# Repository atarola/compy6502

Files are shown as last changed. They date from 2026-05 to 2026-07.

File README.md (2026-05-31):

# compy6502

`compy6502` is an early-stage 6502 homebrew computer project. The long-term
goal is to build enough hardware and firmware to run Tetris on the machine.

The design follows the spirit of Ben Eater-style breadboard/modular 6502
systems for simplicity and debuggability, but uses a different memory map based
on the MMU/address-decoder architecture in `docs/mmu.png`.

The repo currently includes KiCad hardware designs, early ROM bring-up
firmware, build/write scripts, emulator test scaffolding, and architecture
reference images in `docs/`.

## Memory Map

The intended memory map is:

```text
$0000-$BFFF  RAM
$C000-$C0FF  I/O page
$C100-$FFFF  ROM
```

The I/O page is split into four 64-byte device slots:

```text
$C000-$C03F  IO0B
$C040-$C07F  IO1B
$C080-$C0BF  IO2B
$C0C0-$C0FF  IO3B
```

The linker script currently uses `$8000-$FFFF` as the 32 KB EEPROM image range
so CPU addresses map directly to the correct physical offsets on the chip.

## ROM Layout

The intended ROM organization is:

```text
$C100-$C1FF  public jump table
$C200-$DFFF  kernel routines and drivers
$E000-$EFFF  enhanced monitor
$F500-$FFF9  Wozmon fallback monitor
$FFFA-$FFFF  CPU vectors
```

## Credits

- `docs/mmu.png`: Mike McLaren, K8LH.
- `docs/Beater 02b.png`: Mike McLaren, K8LH.

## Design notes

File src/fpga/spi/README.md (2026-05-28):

# SPI Controller

The SPI Controller is a memory-mapped SPI peripheral for a 6502-style bus. It provides byte transfers, four programmable active-low chip-select outputs, and a shared tri-state 8-bit data bus that is only driven during read cycles.

Hardware note: the assembled board has the 6502 read/write strobes crossed relative to the original schematic labels. The FPGA top-level compensates for that wiring so the controller still sees the correct read and write edges.

## 1. Features
- 6502-compatible register interface.
- One-byte SPI transmit and receive register.
- Four active-low SPI chip-select outputs.
- Software-controlled chip-select hold.
- Shared tri-state external data bus.
- MSB-first SPI transfers.

## 2. External Signals
### 2.1 6502 Bus
| Signal | Pin | Direction | Description |
| --- | --- | --- | --- |
| `RESB` | `3` | In, active-low | Reset. |
| `CSB` | `14` | In, active-low | Selects this peripheral. |
| `RDB` | `5` | In, active-low | Read strobe. On the built board, this is the physical wire that the top-level routes to the controller write edge input. |
| `WRB` | `4` | In, active-low | Write strobe. On the built board, this is the physical wire that the top-level routes to the controller read edge input. |
| `REG_SELECT[1]` | `1` | In | Register select bit 1. |
| `REG_SELECT[0]` | `2` | In | Register select bit 0. |
| `DATA[7]` | `6` | Inout | Shared data bus bit 7. |
| `DATA[6]` | `7` | Inout | Shared data bus bit 6. |
| `DATA[5]` | `8` | Inout | Shared data bus bit 5. |
| `DATA[4]` | `9` | Inout | Shared data bus bit 4. |
| `DATA[3]` | `10` | Inout | Shared data bus bit 3. |
| `DATA[2]` | `11` | Inout | Shared data bus bit 2. |
| `DATA[1]` | `12` | Inout | Shared data bus bit 1. |
| `DATA[0]` | `13` | Inout | Shared data bus bit 0. |
| `DATA_OUT` | `15` | Out | High when the controller is driving `DATA[7:0]` toward the 6502 bus. |

### 2.2 SPI Bus
| Signal | Pin | Direction | Description |
| --- | --- | --- | --- |
| `SPI_CSB[0]` | `16` | Out, active-low | SPI chip select 0. |
| `SPI_CSB[1]` | `17` | Out, active-low | SPI chip select 1. |
| `SPI_CSB[2]` | `18` | Out, active-low | SPI chip select 2. |
| `SPI_CSB[3]` | `19` | Out, active-low | SPI chip select 3. |
| `SCK` | `20` | Out | SPI clock. |
| `MOSI` | `21` | Out | Master-out serial data. |
| `MISO` | `22` | In | Master-in serial data. |

### 2.3 Local Indicators
| Signal | Pin | Direction | Description |
| --- | --- | --- | --- |
| `LED` | `LED` | Out | High when any `SPI_CSB[3:0]` bit is low. |

## 3. Register Map
`REG_SELECT[1:0]` selects one of four register addresses.

| Address | Name | Read | Write |
| --- | --- | --- | --- |
| `0x00` | Data | Last received byte | Transmit byte and start transfer |
| `0x01` | Config | Current configuration | Update configuration |
| `0x02` | Status | Transfer status | Ignored |
| `0x03` | Reserved | `0x00` | Ignored |

## 4. Config Register
| Bits | Name | Description |
| --- | --- | --- |
| `1:0` | CS Select | Selects one of four SPI chip-select outputs. |
| `2` | CS Enable | `1` asserts selected chip select. `0` releases all chip selects. |
| `4:3` | Clock Select | Selects one of four SPI clock rates. |
| `7:5` | Reserved | Write `0`. |

Chip-select output when `CS Enable = 1`:

| CS Select | `SPI_CSB[3:0]` |
| --- | --- |
| `0b00` | `0b1110` |
| `0b01` | `0b1101` |
| `0b10` | `0b1011` |
| `0b11` | `0b0111` |

When `CS Enable = 0`, `SPI_CSB[3:0] = 0b1111`.

Clock rate setting:

| Setting | Result |
| --- | --- |
| `0b00` | `125 kHz` |
| `0b01` | `250 kHz` |
| `0b10` | `500 kHz` |
| `0b11` | `1 MHz` |

## 5. Status Register
| Bit | Name | Description |
| --- | --- | --- |
| `0` | Busy | `1` while a byte transfer is active. |
| `7:1` | Reserved | Reads as `0`. |

## 6. Bus Behavior
- The controller drives `DATA[7:0]` only during selected read cycles.
- `DATA_OUT` is high only during selected read cycles.
- During writes and unselected cycles, `DATA[7:0]` is high impedance from the controller side.
- Write effects are visible after a small number of FPGA clock cycles.
- Software should poll the Busy bit before assuming a byte transfer has completed.
- Writes to the Data register while Busy is set are ignored.

## 7. SPI Behavior
- Transfers are one byte at a time.
- Bits shift MSB first.
- Chip select is controlled by the Config register, not automatically by each byte transfer.
- For multi-byte devices, assert chip select, write/read the required bytes, then clear chip select.

## 8. Expected Transaction Example
Example: send command byte `0x9f` to device 0, then read three response bytes.

| Step | Register | RDB | WRB | Value | Expected effect |
| --- | --- | --- | --- | --- | --- |
| 1 | Config `0x01` | `1` | `0` | `0x04` | Assert `SPI_CSB[0]`; `SPI_CSB[3:0] = 0b1110`. |
| 2 | Data `0x00` | `1` | `0` | `0x9f` | Start transfer of command byte. |
| 3 | Status `0x02` | `0` | `1` | Read until Busy is `0` | Wait for command byte to finish. |
| 4 | Data `0x00` | `1` | `0` | `0x00` | Start transfer of first response byte. |
| 5 | Status `0x02` | `0` | `1` | Read until Busy is `0` | Wait for first response byte. |
| 6 | Data `0x00` | `0` | `1` | Read | Read first received byte. |
| 7 | Data `0x00` | `1` | `0` | `0x00` | Start transfer of second response byte. |
| 8 | Status `0x02` | `0` | `1` | Read until Busy is `0` | Wait for second response byte. |
| 9 | Data `0x00` | `0` | `1` | Read | Read second received byte. |
| 10 | Data `0x00` | `1` | `0` | `0x00` | Start transfer of third response byte. |
| 11 | Status `0x02` | `0` | `1` | Read until Busy is `0` | Wait for third response byte. |
| 12 | Data `0x00` | `0` | `1` | Read | Read third received byte. |
| 13 | Config `0x01` | `1` | `0` | `0x00` | Release all chip selects; `SPI_CSB[3:0] = 0b1111`. |

Each Data write shifts one byte out on `MOSI` and captures one byte from `MISO`. For read-only SPI responses, write `0x00` or another device-appropriate dummy byte to clock each response byte in.

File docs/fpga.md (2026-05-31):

# FPGA Development Environment

This project is expected to use a TinyFPGA BX for early SPI interface work. The
TinyFPGA BX uses a Lattice iCE40 FPGA, so the local toolchain is based on the
open-source iCE40 flow.

## Toolchain

Install the core tools with Homebrew:

```sh
brew install icarus-verilog verilator yosys nextpnr-ice40 icestorm surfer
```

The important tools are:

- `iverilog` / `vvp`: quick Verilog simulation.
- `verilator`: stronger linting and compiled simulation for larger tests.
- `yosys`: Verilog synthesis.
- `nextpnr-ice40`: place and route for Lattice iCE40 parts.
- `icepack`: bitstream packing, provided by `icestorm`.
- `surfer`: waveform viewer.

GTKWave is the traditional waveform viewer, but the Homebrew cask is currently
disabled. Use Surfer for waveform viewing unless that changes.

## TinyFPGA Programming From Windows

Build bitstreams from WSL/Ubuntu, but program the TinyFPGA BX from Windows.
WSL USB passthrough is unreliable with the BX bootloader timing.

Install `tinyprog` in Windows PowerShell:

```powershell
py -m pip install --user pipx
py -m pipx ensurepath
pipx install tinyprog
tinyprog --help
```

Close and reopen PowerShell after `ensurepath` if `pipx` is not found.

Build the FPGA target in WSL:

```sh
uv run doit fpga:build -t spi
```

Press reset on the TinyFPGA BX so the bootloader is active, then program the
bitstream from Windows:

```powershell
tinyprog -p "\\wsl.localhost\Ubuntu\home\atarola\code\compy6502\build\fpga\spi\spi.bin"
```

The USB serial device can disappear after programming because the bitstream
disables `USBPU`. Press reset before the next upload.

## Expected Flow

The normal edit/build/check loop is managed through `doit`:

```sh
uv run doit fpga:sim
uv run doit fpga:build
```

By default, non-programming actions run against all targets under `src/fpga/`.
Use `-t` to select one target:

```sh
uv run doit fpga:sim -t spi
uv run doit fpga:build -t spi
```

Supported FPGA actions are:

- `sim`: run the target testbench with Icarus Verilog.
- `synth`: synthesize `top.v` with Yosys.
- `pnr`: place and route with `nextpnr-ice40`.
- `pack`: pack the routed design with `icepack`.
- `build`: run `synth`, `pnr`, and `pack`.

Target directories use this layout:

```text
src/fpga/<target>/
  top.v
  pins.pcf
  *_tb.v
  other_design_modules.v
```

`fpga:sim` runs every `*_tb.v` testbench in the target. Synthesis reads all
`.v` files except testbenches and uses `top` as the top-level module.

The final bitstream for a target is written to:

```text
build/fpga/<target>/<target>.bin
```

For the spi target:

```text
build/fpga/spi/spi.bin
```

Program the TinyFPGA BX from Windows with `tinyprog` rather than passing USB
through WSL.

Conceptually, the flow is:

```text
write Verilog
simulate with iverilog or verilator
inspect waveforms with surfer
synthesize with yosys
place and route with nextpnr-ice40
pack a bitstream with icepack
program the TinyFPGA BX with tinyprog
```

The TinyFPGA BX guide is still useful for board-specific behavior and bootloader
details:

```text
https://tinyfpga.com/bx/guide.html
```

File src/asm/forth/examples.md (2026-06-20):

## Forth

def double 
  dup add
enddef

def next_term
  dup
  rot
  add
enddef

def fibonnacci
  1
  print
  1
  print
  begin
    next_term
    print
    dup
    B520
    eql
  until
enddef

def ifr      
  if 
    5555 print
    return 
  endif
  AAAA print
enddef

def ife
  if
    5555 print
  else
    AAAA print
  endif
enddef

def count
  0
  begin
    dup 5 eql eqz
  while
    print
    dup 1 add
  repeat
enddef

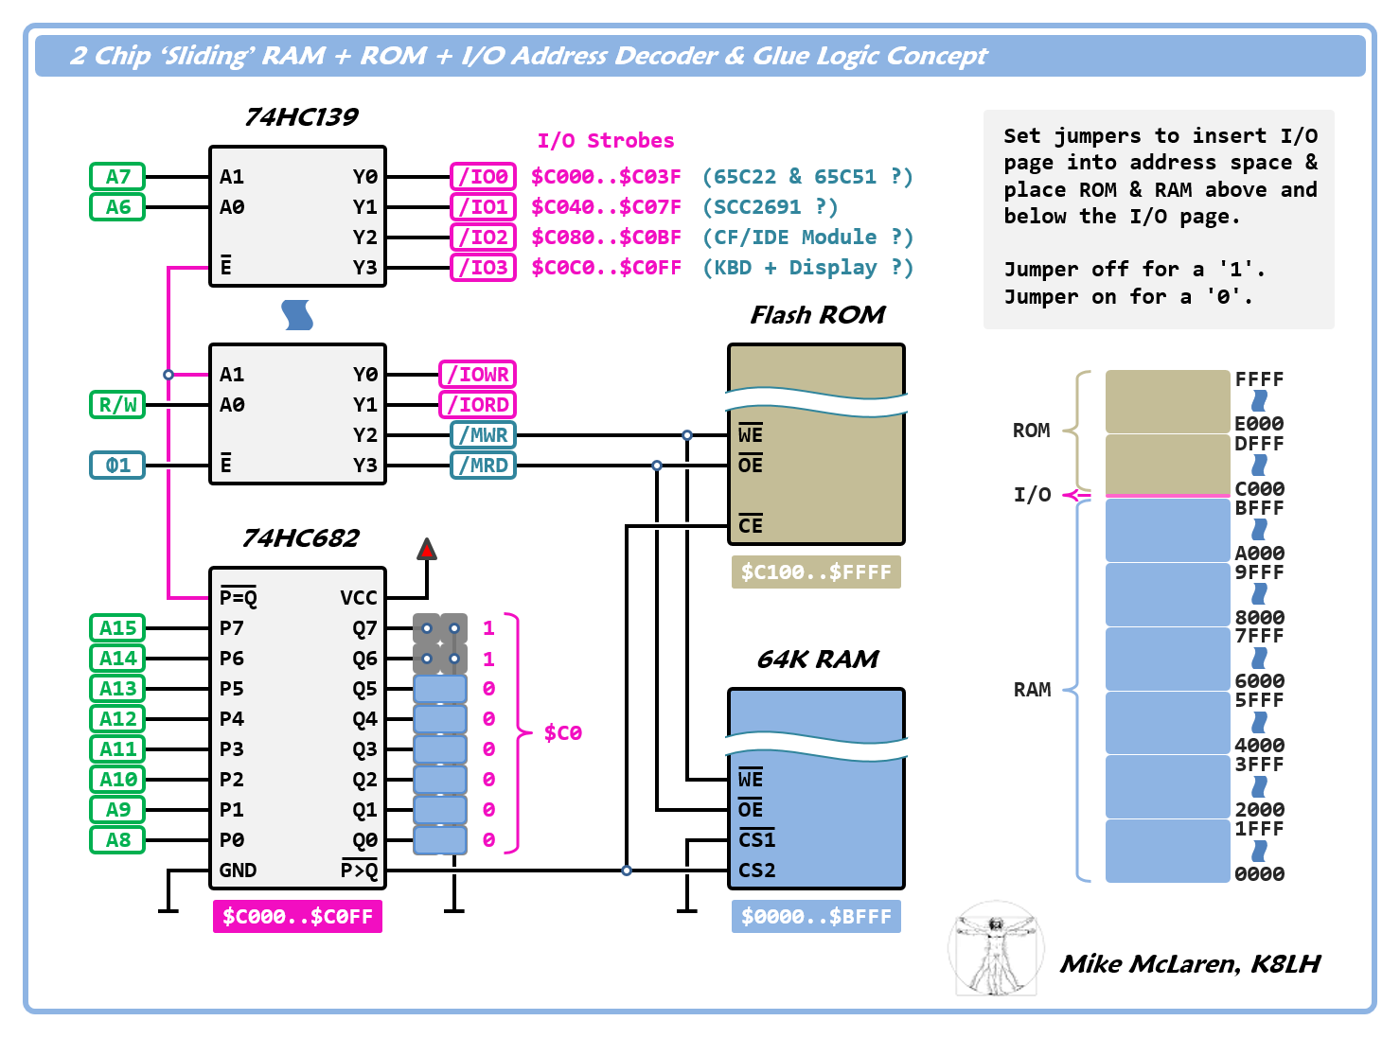
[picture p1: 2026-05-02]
docs/mmu.png

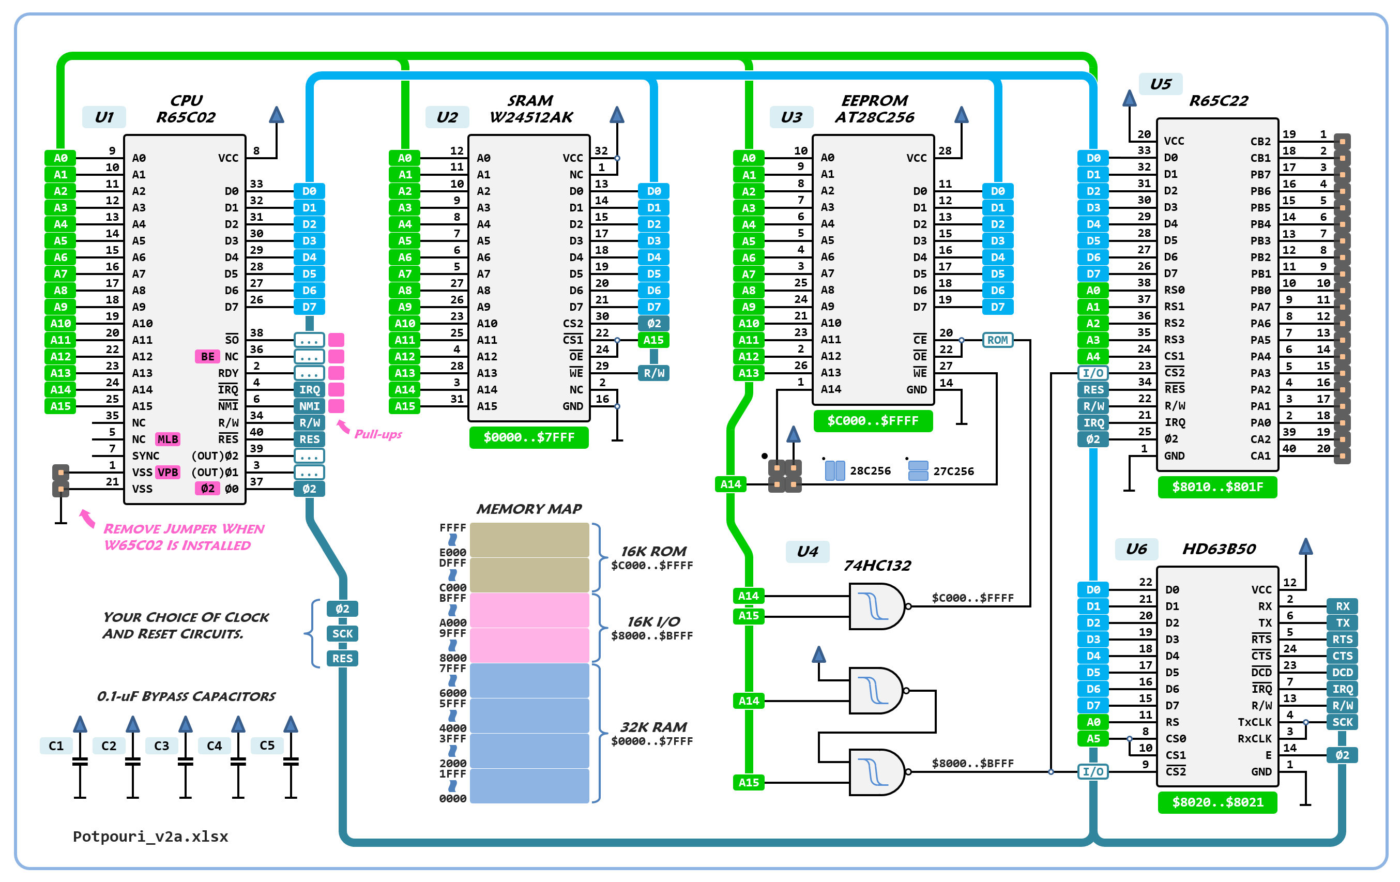
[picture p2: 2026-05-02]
docs/Beater 02b.png

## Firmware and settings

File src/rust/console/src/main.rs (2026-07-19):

#![no_std]
#![no_main]

mod display;
mod eve;
mod host;
mod keyboard;
mod keymap;
mod max3421e;
mod modes;

use embassy_embedded_hal::shared_bus::asynch::spi::SpiDeviceWithConfig;
use embassy_executor::Spawner;
use embassy_rp::bind_interrupts;
use embassy_rp::gpio::{Level, Output};
use embassy_rp::peripherals::{PIO0, SPI1, USB};
use embassy_rp::pio::{InterruptHandler as PioInterruptHandler, Pio};
use embassy_rp::spi::{Async, Config, Spi};
use embassy_rp::usb::{Driver, InterruptHandler};
use embassy_sync::blocking_mutex::raw::CriticalSectionRawMutex;
use embassy_sync::mutex::Mutex;
use embassy_time::Timer;
use embassy_usb_logger::{DummyHandler, LoggerState, UsbLogger};
use static_cell::StaticCell;

use {defmt_rtt as _, panic_probe as _};

bind_interrupts!(struct Irqs {
    PIO0_IRQ_0 => PioInterruptHandler<PIO0>;
    USBCTRL_IRQ => InterruptHandler<USB>;
});

static USB_LOGGER: UsbLogger<1024, DummyHandler> = UsbLogger::new();
static LOGGER_STATE: StaticCell<LoggerState<'static>> = StaticCell::new();

#[embassy_executor::task]
async fn usb_logger_task(state: &'static mut LoggerState<'static>, driver: Driver<'static, USB>) {
    USB_LOGGER.run(state, driver).await;
}

#[embassy_executor::task]
async fn blink_task(mut led: Output<'static>) {
    loop {
        led.set_high();
        Timer::after_millis(500).await;
        led.set_low();
        Timer::after_millis(500).await;
    }
}

static SPI1_BUS: StaticCell<Mutex<CriticalSectionRawMutex, Spi<'static, SPI1, Async>>> =
    StaticCell::new();

#[embassy_executor::main]
async fn main(spawner: Spawner) {
    let p = embassy_rp::init(Default::default());
    let pio0 = Pio::new(p.PIO0, Irqs);

    let spi1 = Spi::new(
        p.SPI1,
        p.PIN_14,
        p.PIN_15,
        p.PIN_8,
        p.DMA_CH0,
        p.DMA_CH1,
        Config::default(),
    );

    let spi1_bus = SPI1_BUS.init(Mutex::new(spi1));

    let usb_driver = Driver::new(p.USB, Irqs);
    let logger_state = LOGGER_STATE.init(LoggerState::new());

    unsafe {
        log::set_logger_racy(&USB_LOGGER).unwrap();
        log::set_max_level_racy(log::LevelFilter::Info);
    }

    spawner
        .spawn(usb_logger_task(logger_state, usb_driver))
        .unwrap();

    let eve_cs = Output::new(p.PIN_29, Level::High);
    let eve_pd = Output::new(p.PIN_6, Level::High);
    let eve_device = SpiDeviceWithConfig::new(spi1_bus, eve_cs, Config::default());

    let max_cs = Output::new(p.PIN_10, Level::High);
    let max_device = SpiDeviceWithConfig::new(spi1_bus, max_cs, Config::default());

    let led = Output::new(p.PIN_13, Level::Low);

    display::display_init(&spawner, eve_device, eve_pd).await;
    keyboard::keyboard_init(&spawner, max_device).await;
    host::host_init(spawner, p.CORE1, pio0, p.PIN_0, p.PIN_1, p.PIN_2, p.PIN_3);
    modes::modes_init(spawner);

    spawner.spawn(blink_task(led)).unwrap();
}

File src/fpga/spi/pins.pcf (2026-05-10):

set_io REG_SELECT[1] A2
set_io REG_SELECT[0] A1

set_io RESB B1
set_io WRB C2
set_io RDB C1

set_io DATA[7] D2
set_io DATA[6] D1
set_io DATA[5] E2
set_io DATA[4] E1
set_io DATA[3] G2
set_io DATA[2] H1
set_io DATA[1] J1
set_io DATA[0] H2

set_io CSB H9

set_io DATA_OUT D9

set_io SPI_CSB[0] D8
set_io SPI_CSB[1] C9
set_io SPI_CSB[2] A9
set_io SPI_CSB[3] B8

set_io SCK A8
set_io MOSI B7
set_io MISO A7

set_io LED B3
set_io USBPU A3
set_io CLK B2

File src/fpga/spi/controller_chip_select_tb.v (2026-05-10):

`timescale 1ns / 1ps

/**
 * Spec: controller chip-select decode.
 *
 * Verify that spi_csb stays inactive when conf[2] is low and decodes conf[1:0]
 * when conf[2] is high.
 */
module controller_chip_select_tb;
  reg clk = 0;
  reg resb = 1;
  reg csb = 1;
  reg rdb = 1;
  reg wrb = 1;
  reg [1:0] reg_select = 2'b00;
  reg miso = 0;
  reg [7:0] cpu_data_in = 8'h00;

  reg [3:0] spi_csb_0;
  reg [3:0] spi_csb_1;
  reg [3:0] spi_csb_2;
  reg [3:0] spi_csb_3;

  wire [7:0] cpu_data_out;
  wire cpu_data_oeb;
  wire sck;
  wire mosi;
  wire [3:0] spi_csb;


  controller uut (
      .clk(clk),
      .resb(resb),
      .csb(csb),
      .rdb(rdb),
      .wrb(wrb),
      .reg_select(reg_select),
      .cpu_data_in(cpu_data_in),
      .cpu_data_out(cpu_data_out),
      .cpu_data_oeb(cpu_data_oeb),
      .sck(sck),
      .mosi(mosi),
      .miso(miso),
      .spi_csb(spi_csb)
  );

  always #31.25 clk = ~clk;

  task run_controller;
    input [7:0] con;
    output [3:0] csb_value;
    begin
      @(posedge clk);
      reg_select = uut.RegConf;
      csb = 0;
      rdb = 1;
      wrb = 0;
      cpu_data_in = con;

      repeat (3) @(posedge clk);

      @(posedge clk);
      wrb = 1;

      @(posedge clk);
      reg_select = uut.RegData;
      csb = 0;
      rdb = 1;
      wrb = 0;
      cpu_data_in = 8'hFF;

      repeat (3) @(posedge clk);

      reg_select = uut.RegStatus;
      csb = 0;
      rdb = 0;
      wrb = 1;

      repeat (3) @(posedge clk);

      wait (cpu_data_out[0] == 1'b1);
      csb_value = spi_csb;

      wait (cpu_data_out[0] == 1'b0);
      if (cpu_data_out !== 8'h00) begin
        $display("FAIL: expected status busy=0 after transfer completes, got %b", cpu_data_out);
        $finish;
      end
    end
  endtask

  initial begin
    repeat (10000) @(posedge clk);
    $display("FAIL: timeout");
    $finish;
  end

  initial begin
    $dumpfile("build/fpga/spi/controller_chip_select_tb.vcd");
    $dumpvars(0, controller_chip_select_tb);

    @(posedge clk);
    resb = 0;
    @(posedge clk);
    resb = 1;

    // default chip select
    if (spi_csb !== 4'b1111) begin
      $display("FAIL: expected spi_csb to be 1111, got %b", spi_csb);
      $finish;
    end

    // spi_csb = 1110 (conf[2]=1, conf[1:0]=00)
    run_controller(8'h04, spi_csb_0);
    if (spi_csb_0 !== 4'b1110) begin
      $display("FAIL: expected spi_csb to be 1110, got %b", spi_csb_0);
      $finish;
    end

    // spi_csb = 1101 (conf[2]=1, conf[1:0]=01)
    run_controller(8'h05, spi_csb_1);
    if (spi_csb_1 !== 4'b1101) begin
      $display("FAIL: expected spi_csb to be 1101, got %b", spi_csb_1);
      $finish;
    end

    // spi_csb = 1011 (conf[2]=1, conf[1:0]=10)
    run_controller(8'h06, spi_csb_2);
    if (spi_csb_2 !== 4'b1011) begin
      $display("FAIL: expected spi_csb to be 1011, got %b", spi_csb_2);
      $finish;
    end

    // spi_csb = 0111 (conf[2]=1, conf[1:0]=11)
    run_controller(8'h07, spi_csb_3);
    if (spi_csb_3 !== 4'b0111) begin
      $display("FAIL: expected spi_csb to be 0111, got %b", spi_csb_3);
      $finish;
    end

    // clear conf[2] and verify default inactive chip select
    @(posedge clk);
    reg_select = uut.RegConf;
    csb = 0;
    rdb = 1;
    wrb = 0;
    cpu_data_in = 8'h00;
    repeat (3) @(posedge clk);
    wrb = 1;
    repeat (3) @(posedge clk);

    if (spi_csb !== 4'b1111) begin
      $display("FAIL: expected spi_csb to be 1111, got %b", spi_csb);
      $finish;
    end

    $display("PASS");
    $finish;
  end
endmodule

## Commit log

2019-11-14 added timer info
2021-12-27 removed acia, added spi
2026-05-02 reboot project
    [backplane.kicad_pcb, backplane.kicad_sch, cpu.kicad_pcb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]
2026-05-02 moved the python stuff to modern frameworks
2026-05-04 integrated wozmon, updated kicad to specify phi1o
    [backplane.kicad_pcb, backplane.kicad_sch, cpu.kicad_pcb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]
2026-05-04 added acia board
    [ACIA.kicad_pcb, ACIA.kicad_sch, template.kicad_pcb]
2026-05-05 designed the front panel
    [panel.kicad_pcb, panel.kicad_sch]
2026-05-07 make room for verilog
    [ACIA.kicad_pcb, cpu.kicad_pcb, panel.kicad_pcb]
2026-05-07 updated fpga framework to handle multiple modules
2026-05-09 removed spi chip select from the engine
2026-05-10 drive a pin for handling level shifting
2026-05-10 added board numbers to pin descriptions
2026-05-11 added arduino test harness
2026-05-14 version 1 of the SPI board
    [spi.kicad_pcb, spi.kicad_sch]
2026-05-15 setup eventual console output
    [de9.kicad_pcb, de9.kicad_sch, spi.kicad_pcb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]
2026-05-21 added spi and via boards
    [de9.kicad_pcb, de9.kicad_sch, spi.kicad_pcb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]
2026-05-25 prepping for control flow
2026-05-28 got the spi controller controlling
2026-05-29 finished up the fram driver
2026-05-31 added tests for SPI and FRAM
2026-06-05 wrong spi host
2026-06-06 display_task doesnt need the pd pin
2026-06-13 finished keyboard wiring
2026-06-16 tracked down the spi FF bug
2026-06-19 remove the arduino code
2026-07-07 had to rebuild SPI in PIO :/
    [console.kicad_pcb, console.kicad_sch]
2026-07-18 Mode switching (#1)
2026-07-18 load bearing logs :/
